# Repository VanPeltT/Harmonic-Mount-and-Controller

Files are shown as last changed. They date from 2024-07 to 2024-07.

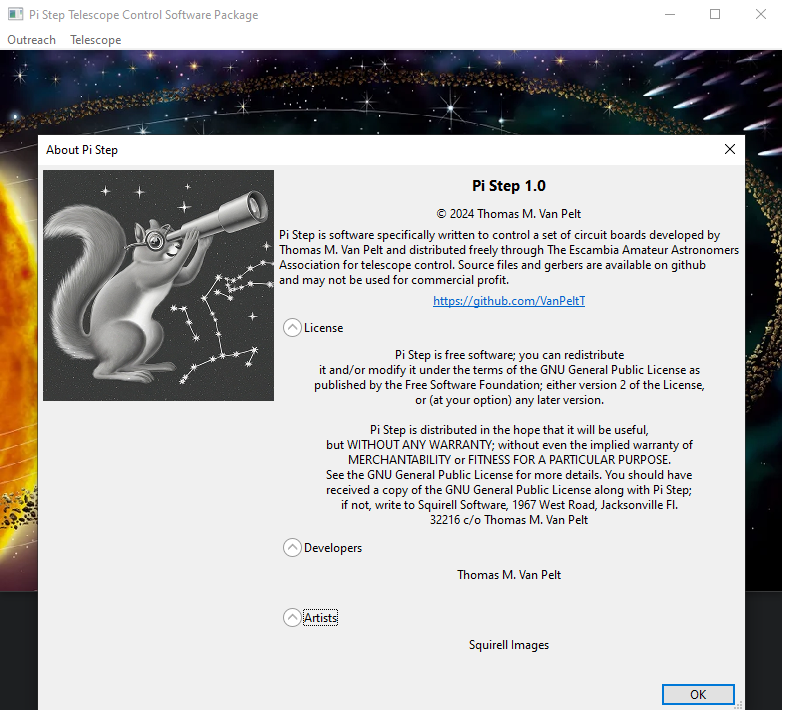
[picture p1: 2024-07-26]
Bonus And Future/Pi Step About.png

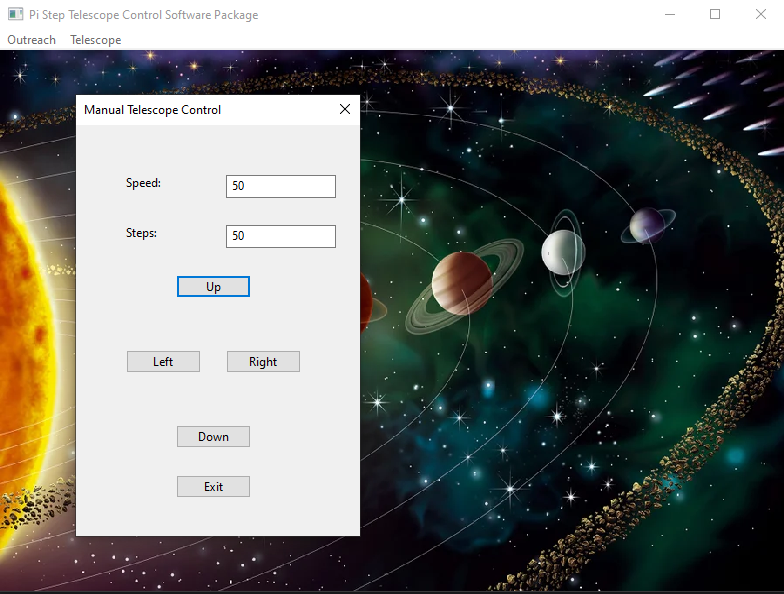
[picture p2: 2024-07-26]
Bonus And Future/Pi Step Manual Control.png

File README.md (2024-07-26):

# Harmonic Drive Telescope Mounts
# A DIY Approach to Precision Astronomical Viewing and Astrophotography
 
 This project, developed by Thomas Van Pelt and Greg Booher, consists of two
 harmonic drive telescope mounts designed for precise astronomical observations. 
 The project showcases both a robust, aluminum-based mount and a more 
 lightweight, entirely 3D-printed variant.

# Overview

  Target Audience: This document is intended for hobbyists, makers, and astronomers 
  interested in building their own high-performance telescope mounts.

# Project Goals:

  Develop affordable, customizable telescope mounts using harmonic drive technology.
  Offer a lightweight and portable 3D-printed option.
  Provide detailed documentation and open-source designs for community use.
  Achieve precise pointing and tracking for astrophotography applications.

# Unique Selling Points:

  Cost-effective: Harmonic drive technology offers high precision at a reasonable 
      cost compared to traditional gear drives.
  Customizable: Modular design allows for adaptations based on telescope weight 
      and user needs.
  Open-source: Hardware and software designs are freely available for modification 
      and improvement.

# Mounts Description

# Mount 1: Aluminum Anodized Mount

  Material: Aluminum (anodized by Greg Booher)
  Motors: 2 NEMA 17 motors with a 27:1 gearbox
  Harmonic Drive: CSF-17-100-2UH-LW with a 100:1 reduction
  Controllers: TMC2209 stepper controllers
  Microcontroller: Teensy 4.0 running OnStep
  Connectivity: Bluetooth and WiFi
  Design Contributions:
    Greg Booher: Machining and Anodizing the aluminum parts
    Thomas Van Pelt: Designing and creating the covers and printed circuit boards

# Mount 2: 3D Printed Mount

  Material: CF-PETG (Carbon Fiber Polyethylene Terephthalate Glycol)
  Motors: 2 NEMA 17 motors with a 30:1 harmonic drive
  Controllers: Same PCB control board as the larger mount
  Connectivity: Bluetooth and WiFi
  Design Contributions: Entirely designed and 3D printed

# Development Timeline

  The project has been under development for over six months and was demonstrated 
  to the Escambia Amateur Astronomy Association in July 2024.

# Future Work
  Thomas Van Pelt plans to further develop the larger mount, integrating it with a 
  custom PCB and software specifically designed for the Raspberry Pi, enhancing the 
  mount's control capabilities and user interface.

# Getting Started

# Prerequisites:

  Teensy 4.0
  TMC2209 stepper controllers
  NEMA 17 motors
  CSF-17-100-2UH-LW harmonic drive for the aluminum mount (or equivalent 100:1 harmonic drive)
  30:1 harmonic drive for the 3D printed mount
  OnStep firmware
  Bluetooth and WiFi modules
  
# Assembly Instructions:

  1. Assemble the aluminum frame.
  2. Install the NEMA 17 motors and the 27:1 gearbox.
  3. Integrate the CSF-17-100-2UH-LW harmonic drive.
  4. Connect the TMC2209 stepper controllers to the Teensy 4.0.
  5. Connect the Bluetooth and WiFi modules to the Teensy 4.0.
  6. Upload OnStep firmware to the Teensy 4.0.
  7. Install the covers and PCBs designed by Thomas.

# Usage:

  1. Power on the system.
  2. Connect the mount to your computer or control device via Bluetooth or WiFi.
  3. Use OnStep software to control the telescope mount. (OnStep download and 
      configuration instructions can be found online)
  4. Adjust settings as necessary for precise astronomical tracking and observation.

# Contribution

  Contributions to further enhance the mounts are welcome. Please fork the 
  repository and submit pull requests.

# License

  This project is licensed under the MIT License.

  For more detailed information, please refer to the documentation in the repository or contact the developers:

  Thomas Van Pelt
  Greg Booher
  
  Happy Stargazing!

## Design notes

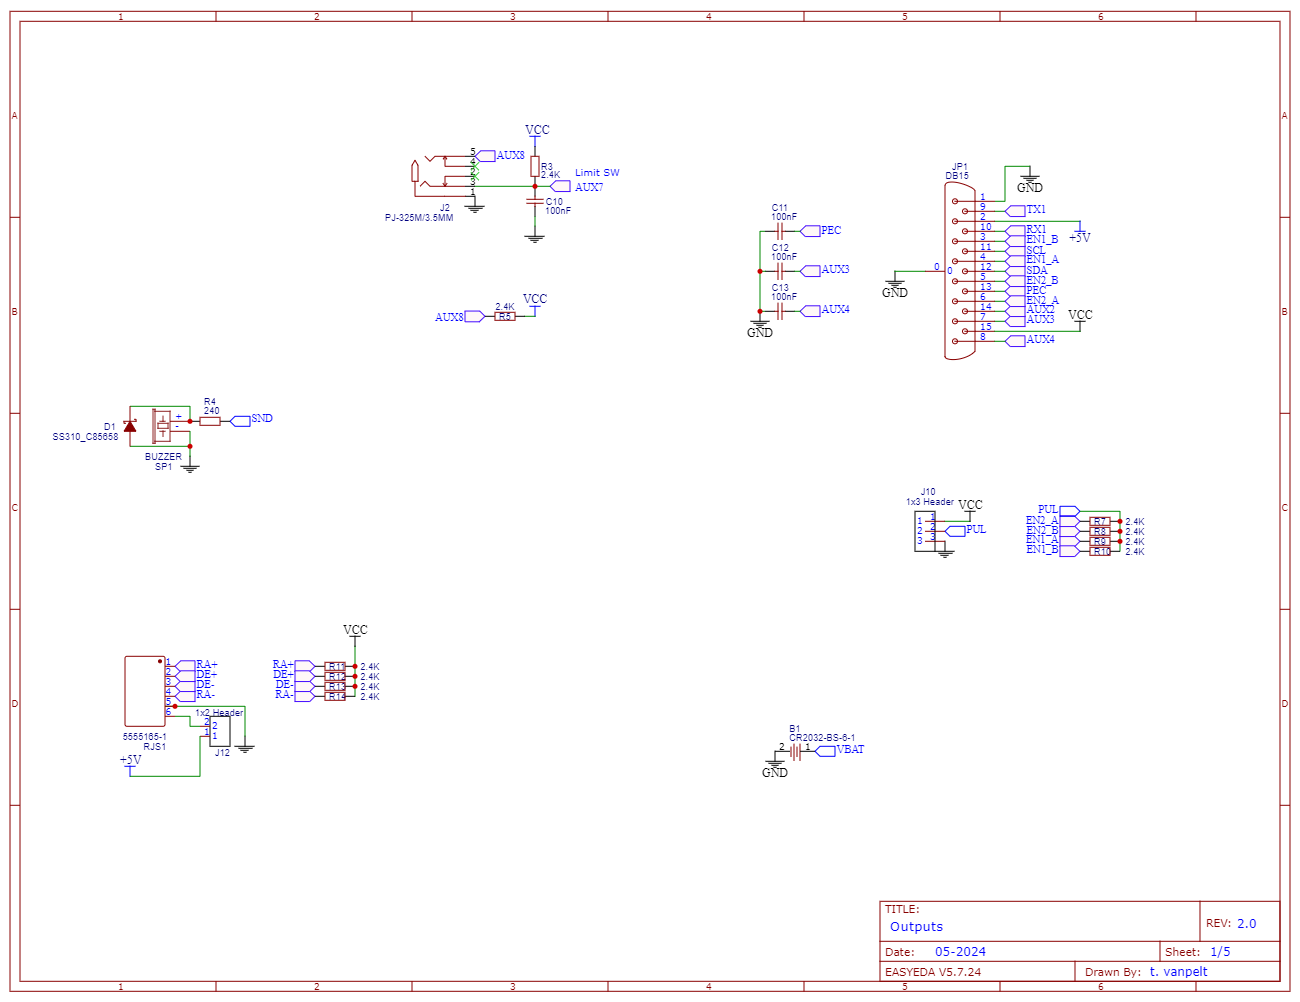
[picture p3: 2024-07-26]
Electronics/Outputs.png

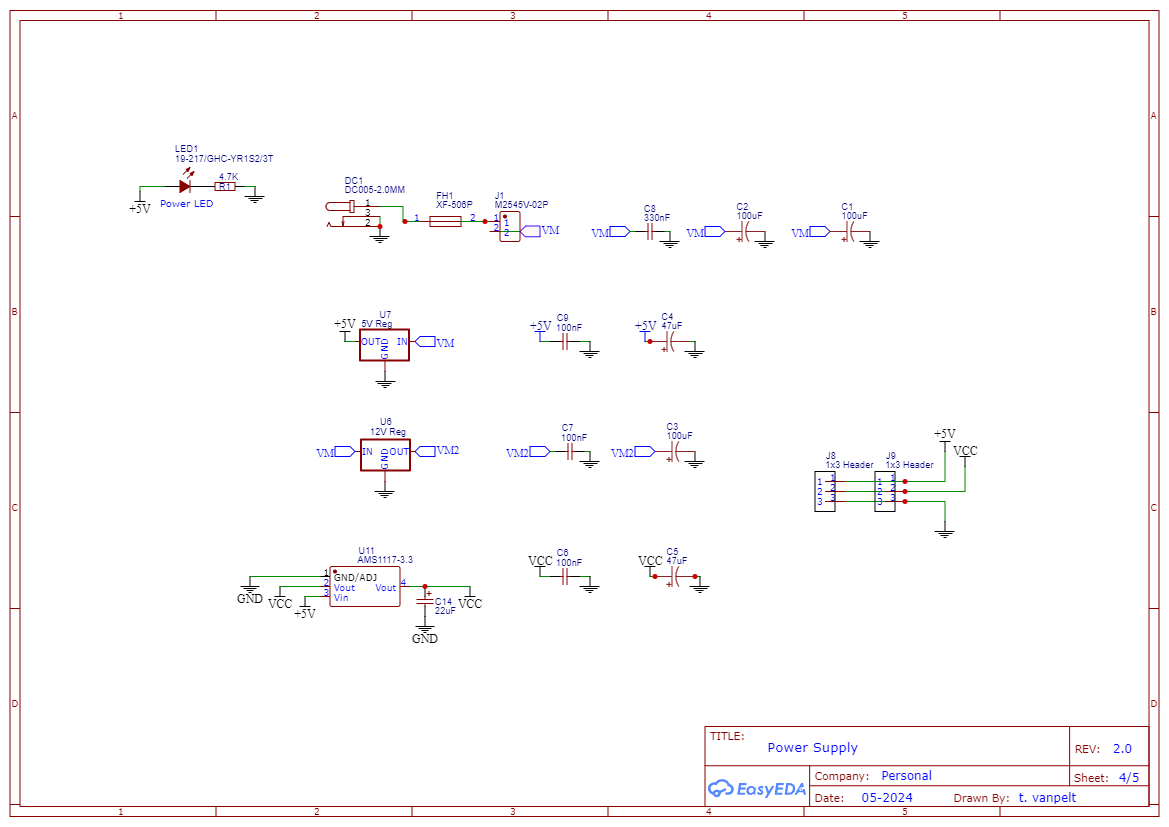
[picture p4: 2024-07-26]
Electronics/PowerSupply.png

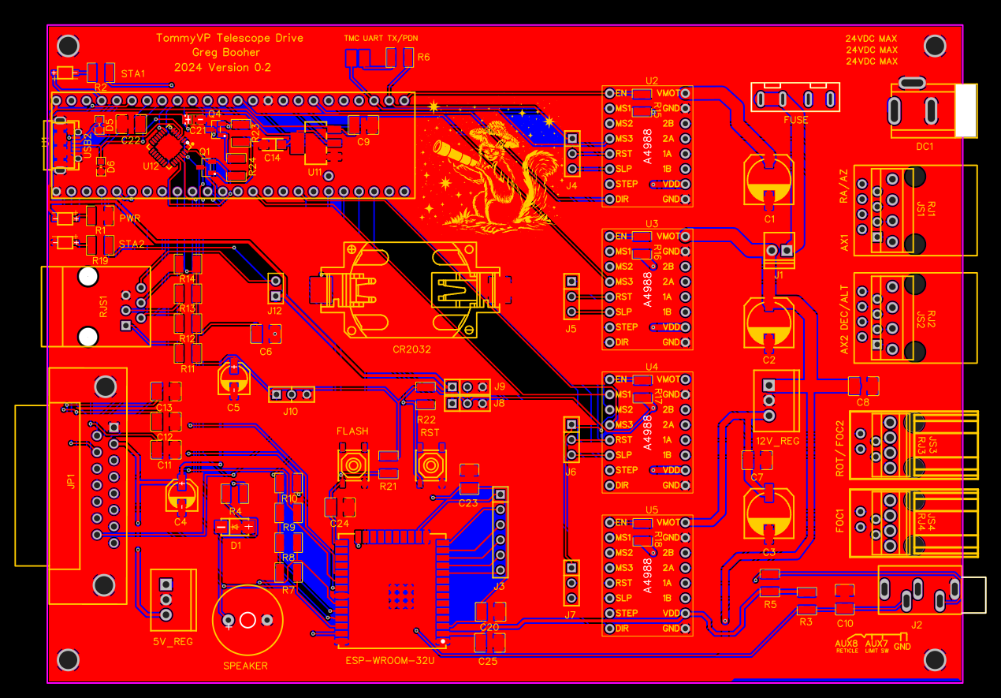
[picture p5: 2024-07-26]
Electronics/PCB_New-Board_2024-07-25.png

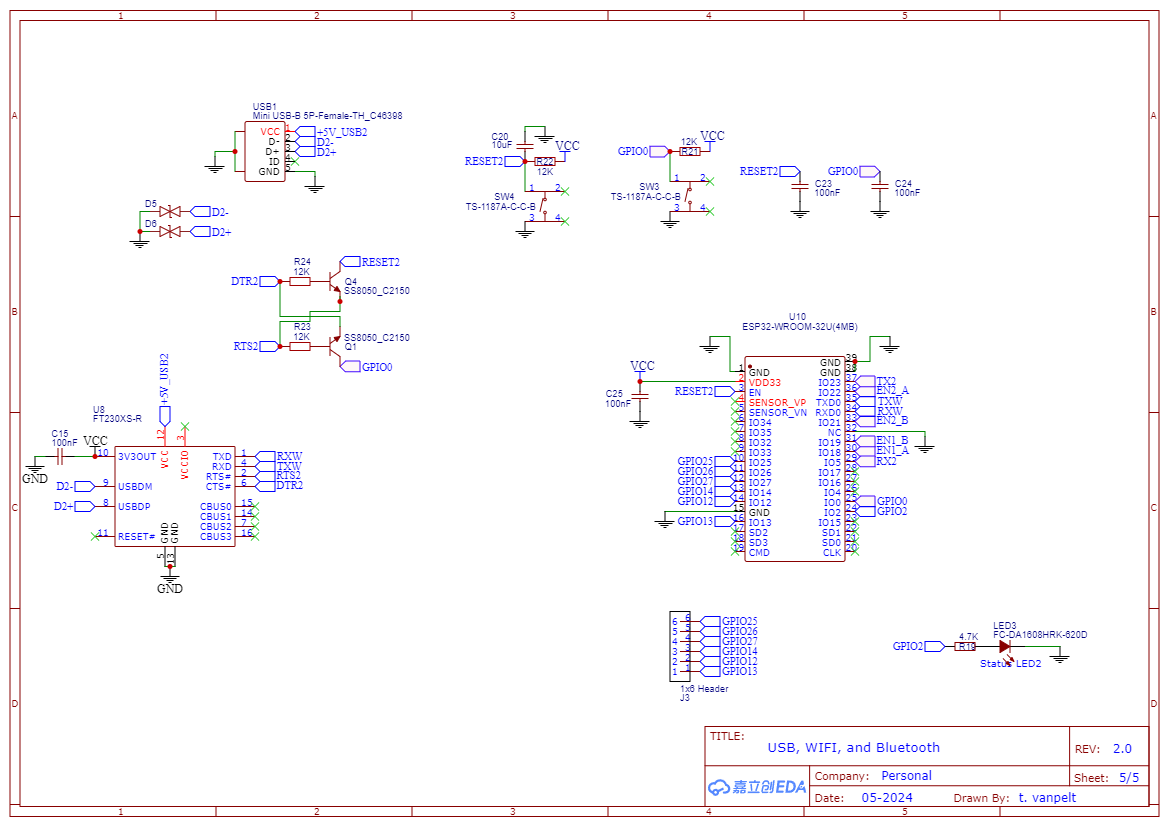
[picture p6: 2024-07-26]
Electronics/USBWIFIBT.png

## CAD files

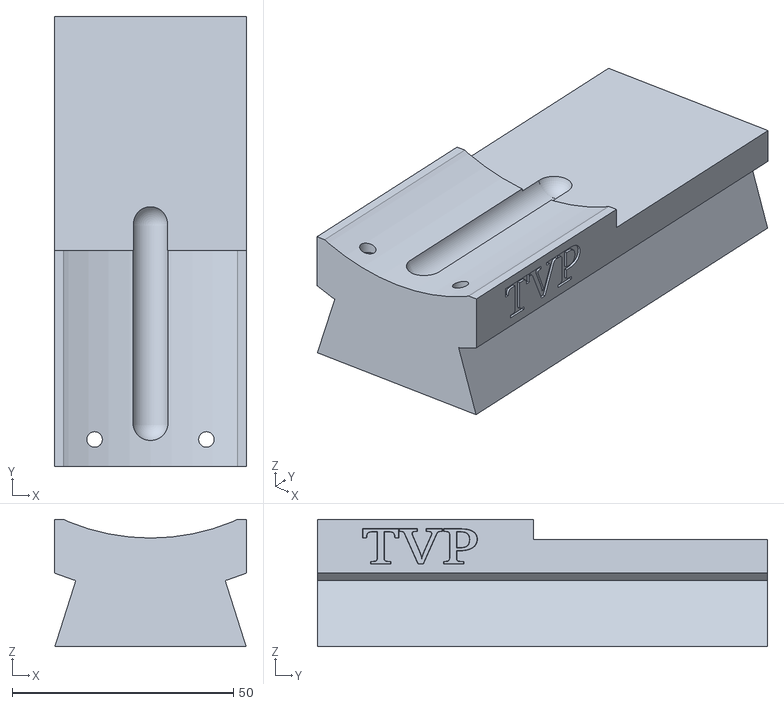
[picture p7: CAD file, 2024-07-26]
Bonus And Future/Orange-Tube-C90_Mount.stl
43.4 x 101.6 x 28.7

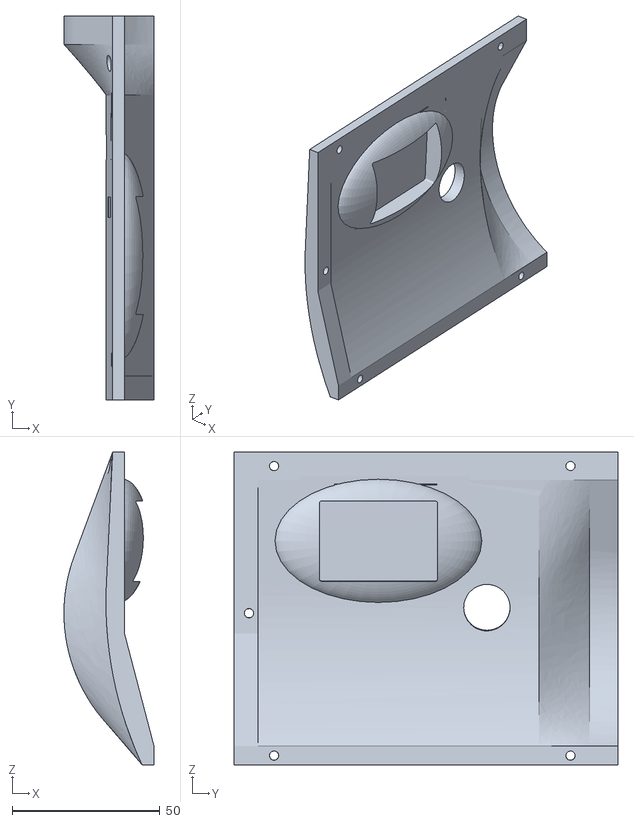
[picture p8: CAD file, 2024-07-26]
Harmonic Mount/3D Gerbers for Harmonic Mount/RA Shell Right.stl
30.5 x 129.8 x 105.9

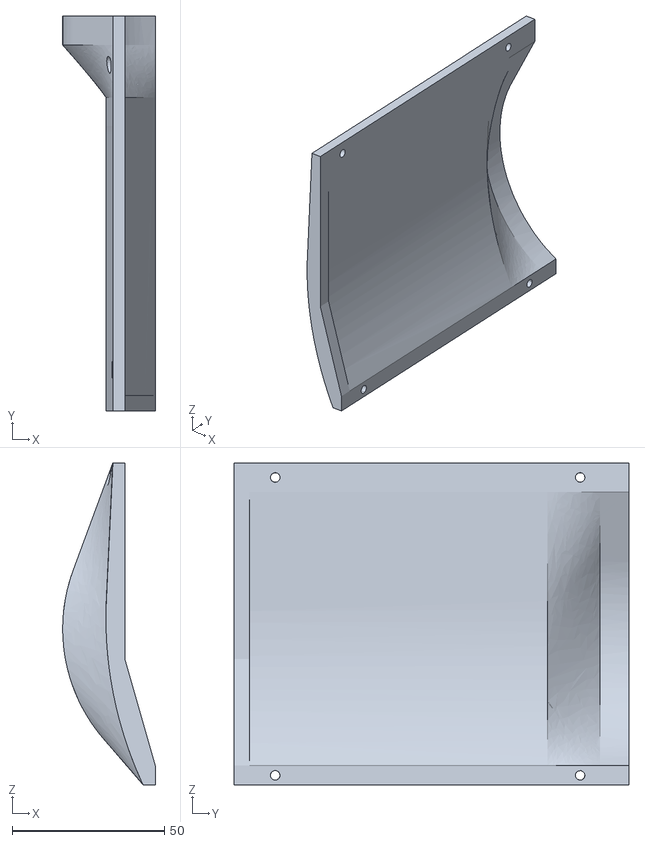
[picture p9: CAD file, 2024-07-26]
Harmonic Mount/3D Gerbers for Harmonic Mount/DEC Shell Right.stl
30.5 x 129.8 x 105.9

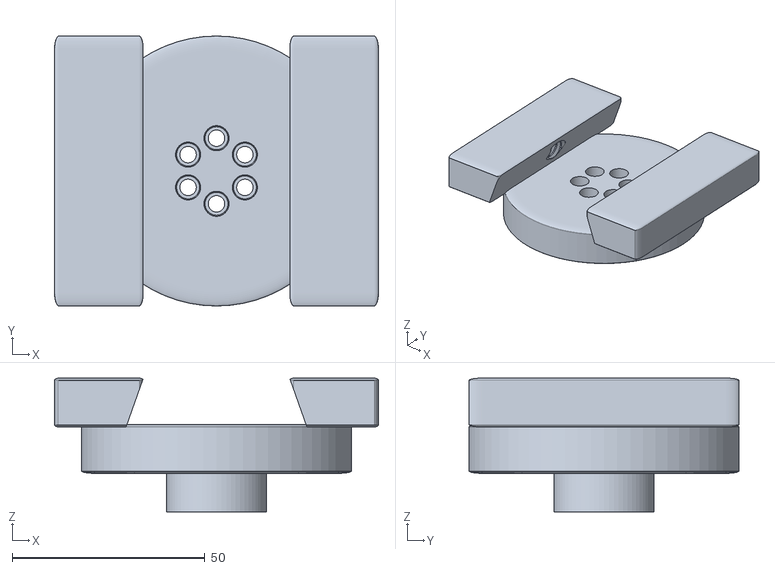
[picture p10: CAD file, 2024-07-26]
Mini Mount/Mini Mount Head 2.stl
84.0 x 70.0 x 34.7

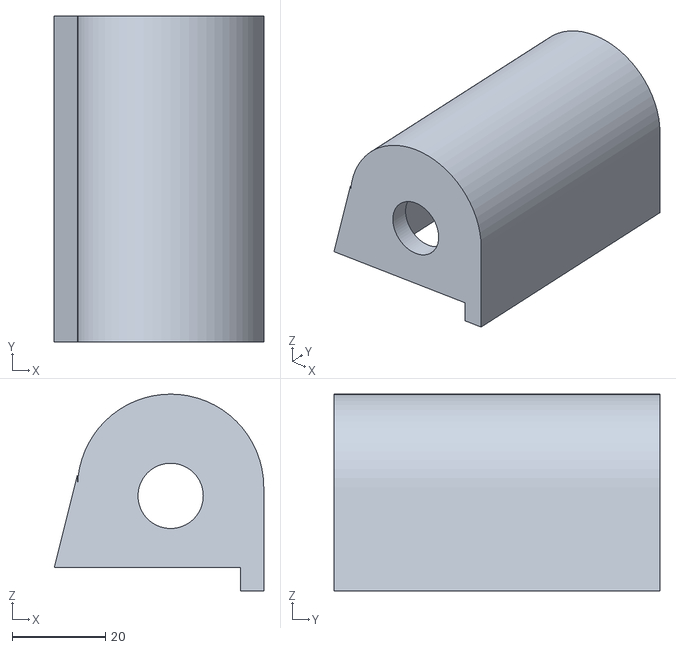
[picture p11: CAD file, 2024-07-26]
Mini Mount/Mini Mount Brace.stl
45.0 x 70.0 x 42.2

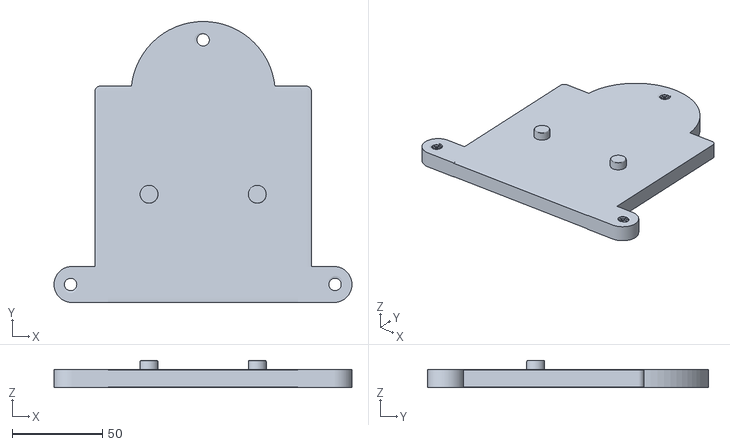
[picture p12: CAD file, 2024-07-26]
Mini Mount/Mini Mount Level Base.stl
165.2 x 155.8 x 15.0

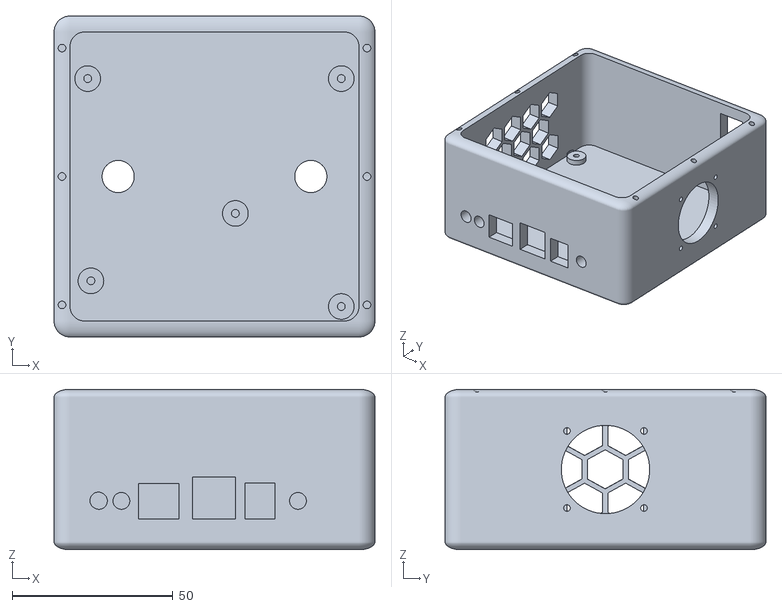
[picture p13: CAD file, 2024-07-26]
Mini Mount/Mini Mount Electronics Housing.stl
100.0 x 100.0 x 50.0

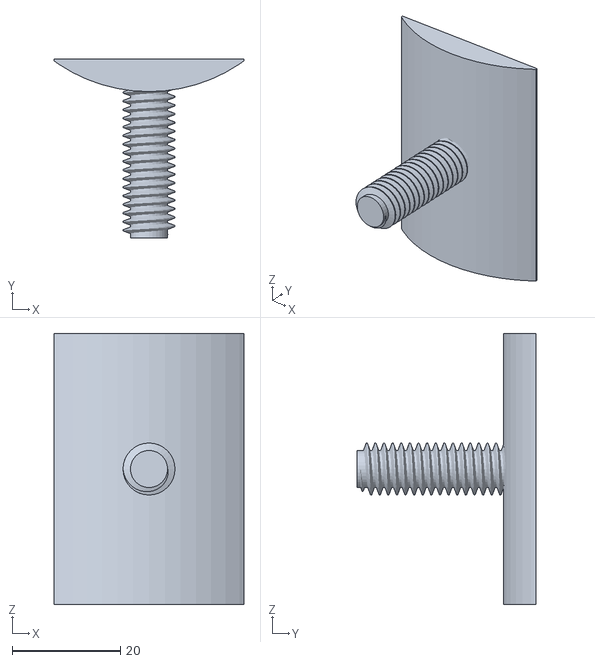
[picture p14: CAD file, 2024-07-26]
Mini Mount/Mini Mount Axis.stl
35.0 x 33.0 x 50.0

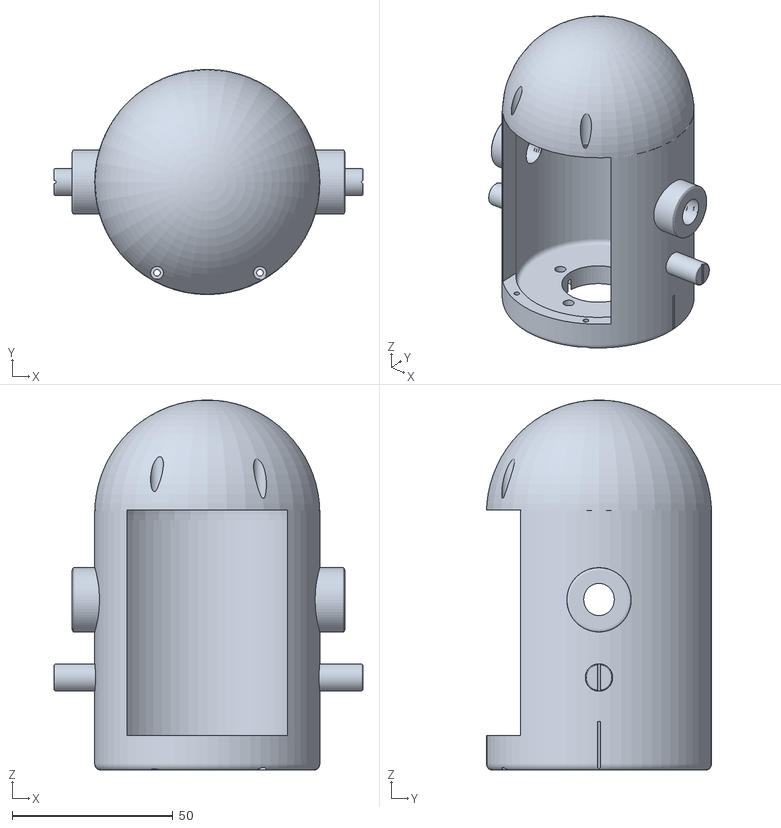
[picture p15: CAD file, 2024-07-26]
Mini Mount/Mini Mount Tail.stl
96.0 x 70.0 x 115.0

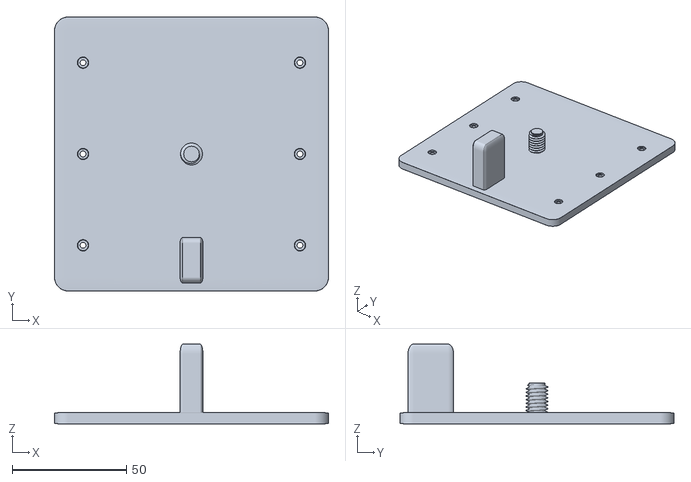
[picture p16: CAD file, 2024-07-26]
Mini Mount/Mini Mount Electronics Cover.stl
120.0 x 120.0 x 35.0

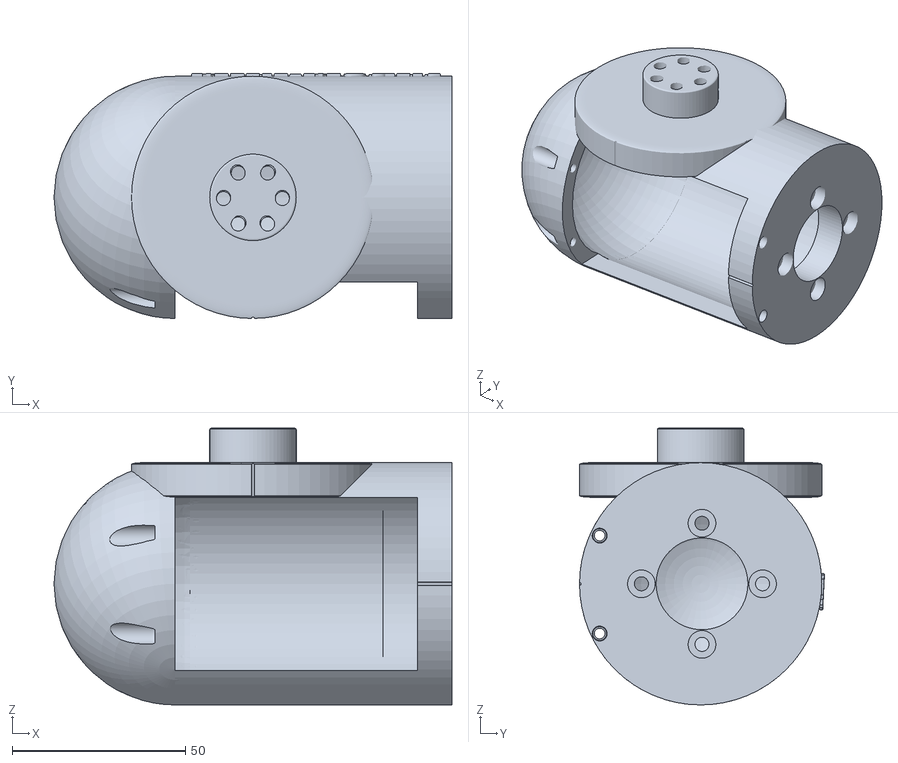
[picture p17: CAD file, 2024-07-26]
Mini Mount/Mini Mount Head 1.stl
115.0 x 70.8 x 80.0

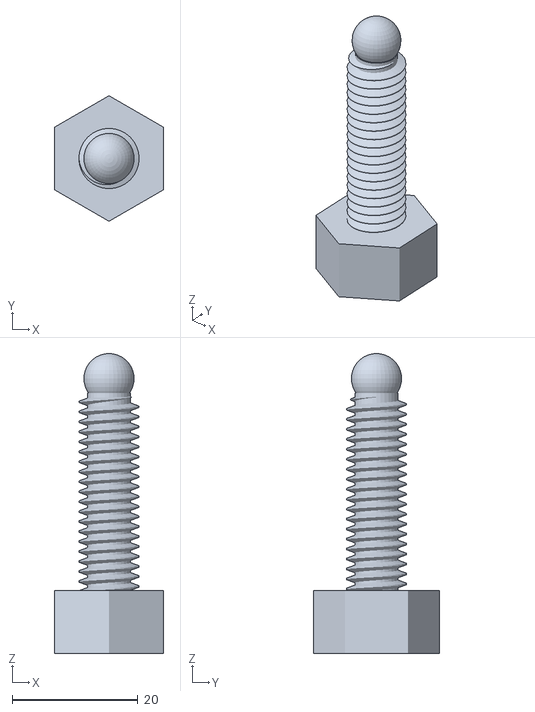
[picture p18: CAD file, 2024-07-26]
Mini Mount/Mini Mount Screw.stl
17.3 x 20.0 x 47.8

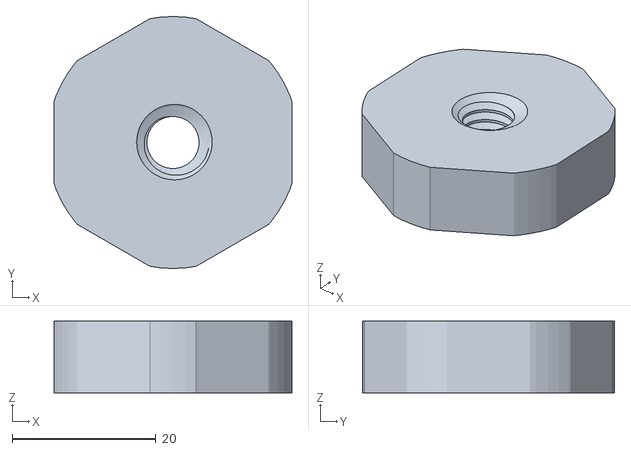
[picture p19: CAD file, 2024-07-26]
Mini Mount/Mini Mount Nut.stl
33.0 x 35.0 x 10.00

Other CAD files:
Harmonic Mount/3D Gerbers for Harmonic Mount/DEC Shell with Aviation Port.stl

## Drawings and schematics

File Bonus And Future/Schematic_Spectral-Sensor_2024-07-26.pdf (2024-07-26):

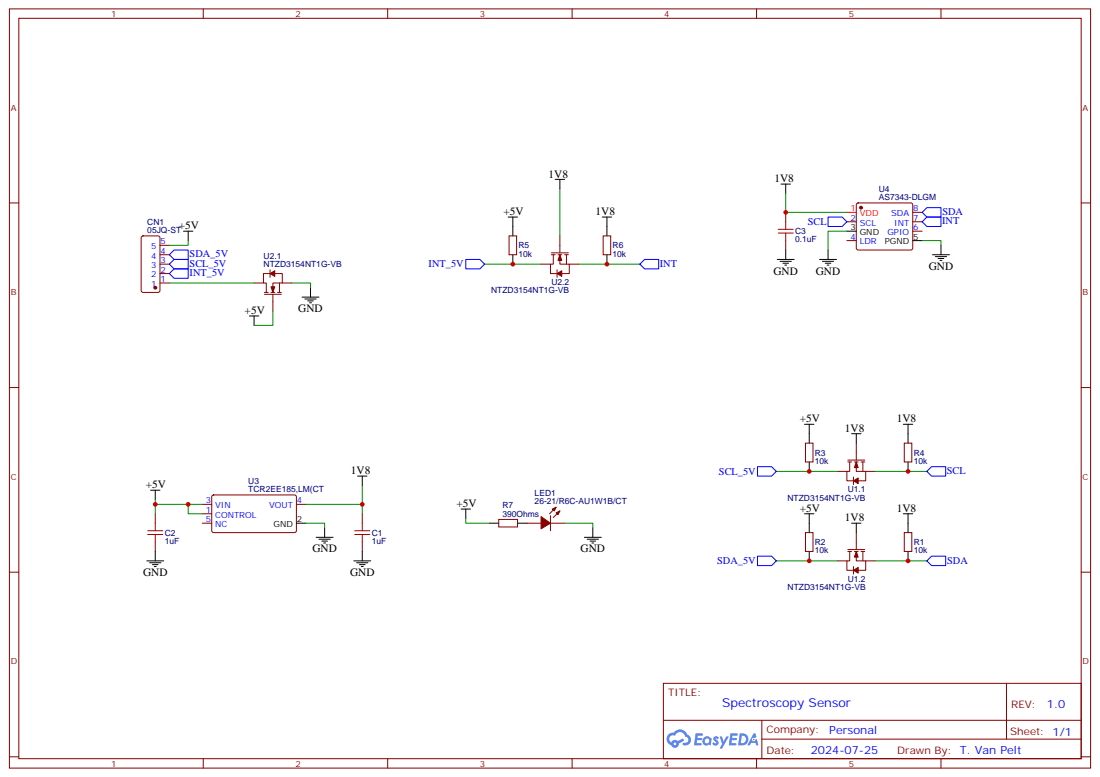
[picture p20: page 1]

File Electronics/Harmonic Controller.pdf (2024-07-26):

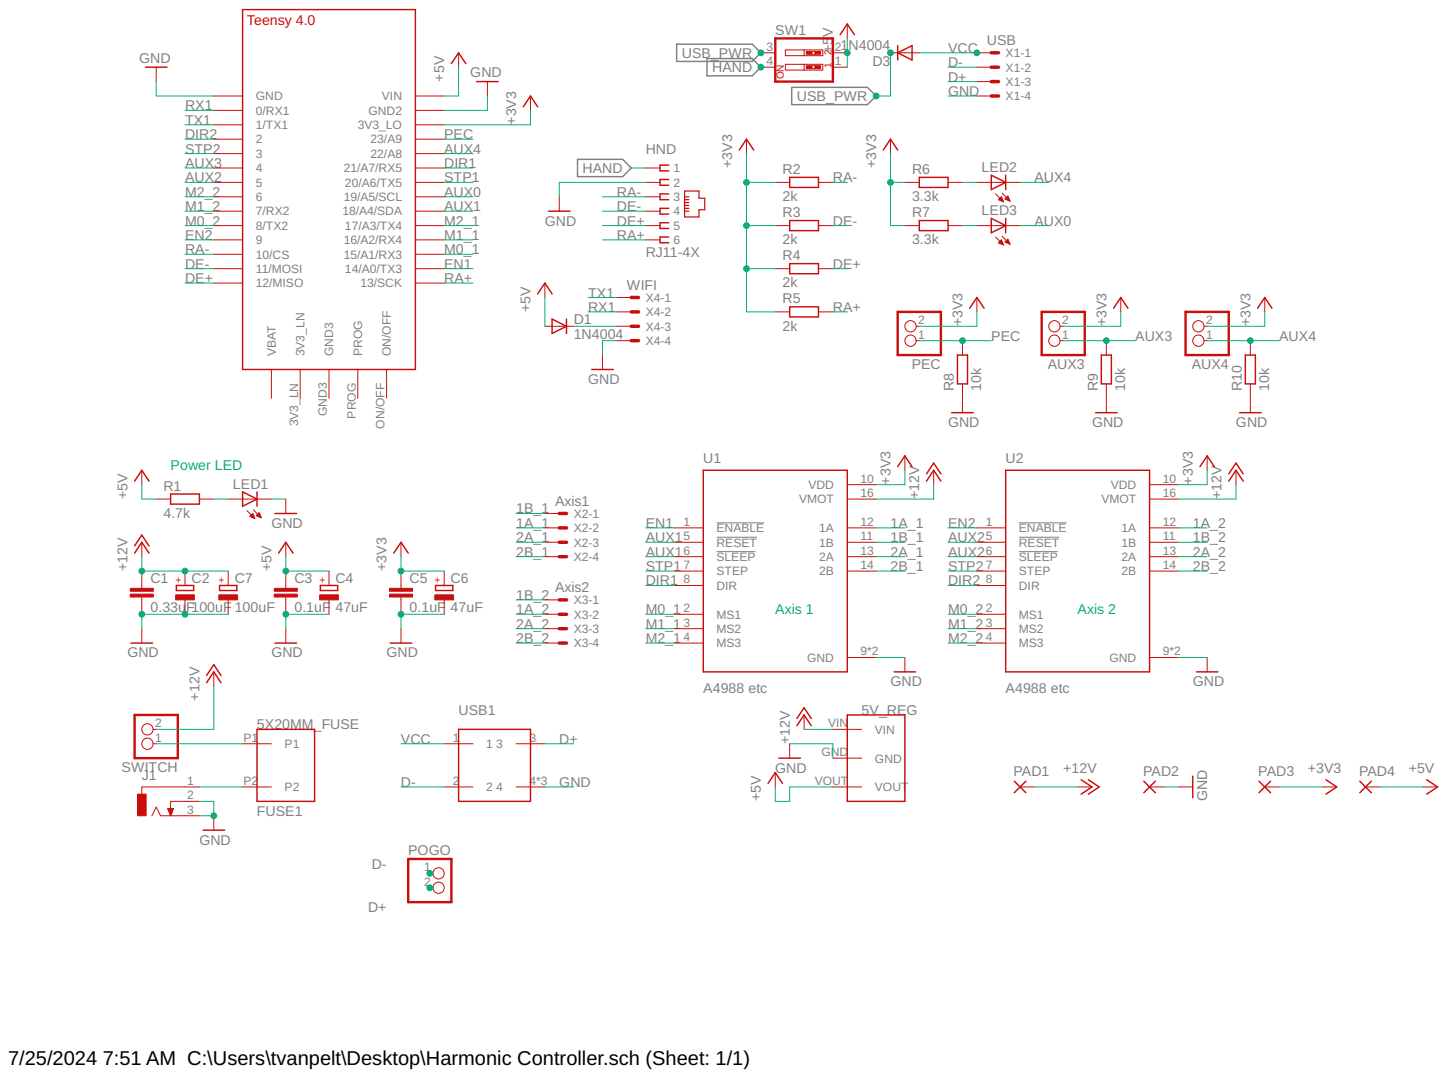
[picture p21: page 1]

ON/OFF

7/25/2024 7:51 AM C:\Users\tvanpelt\Desktop\Harmonic Controller.sch (Sheet: 1/1)

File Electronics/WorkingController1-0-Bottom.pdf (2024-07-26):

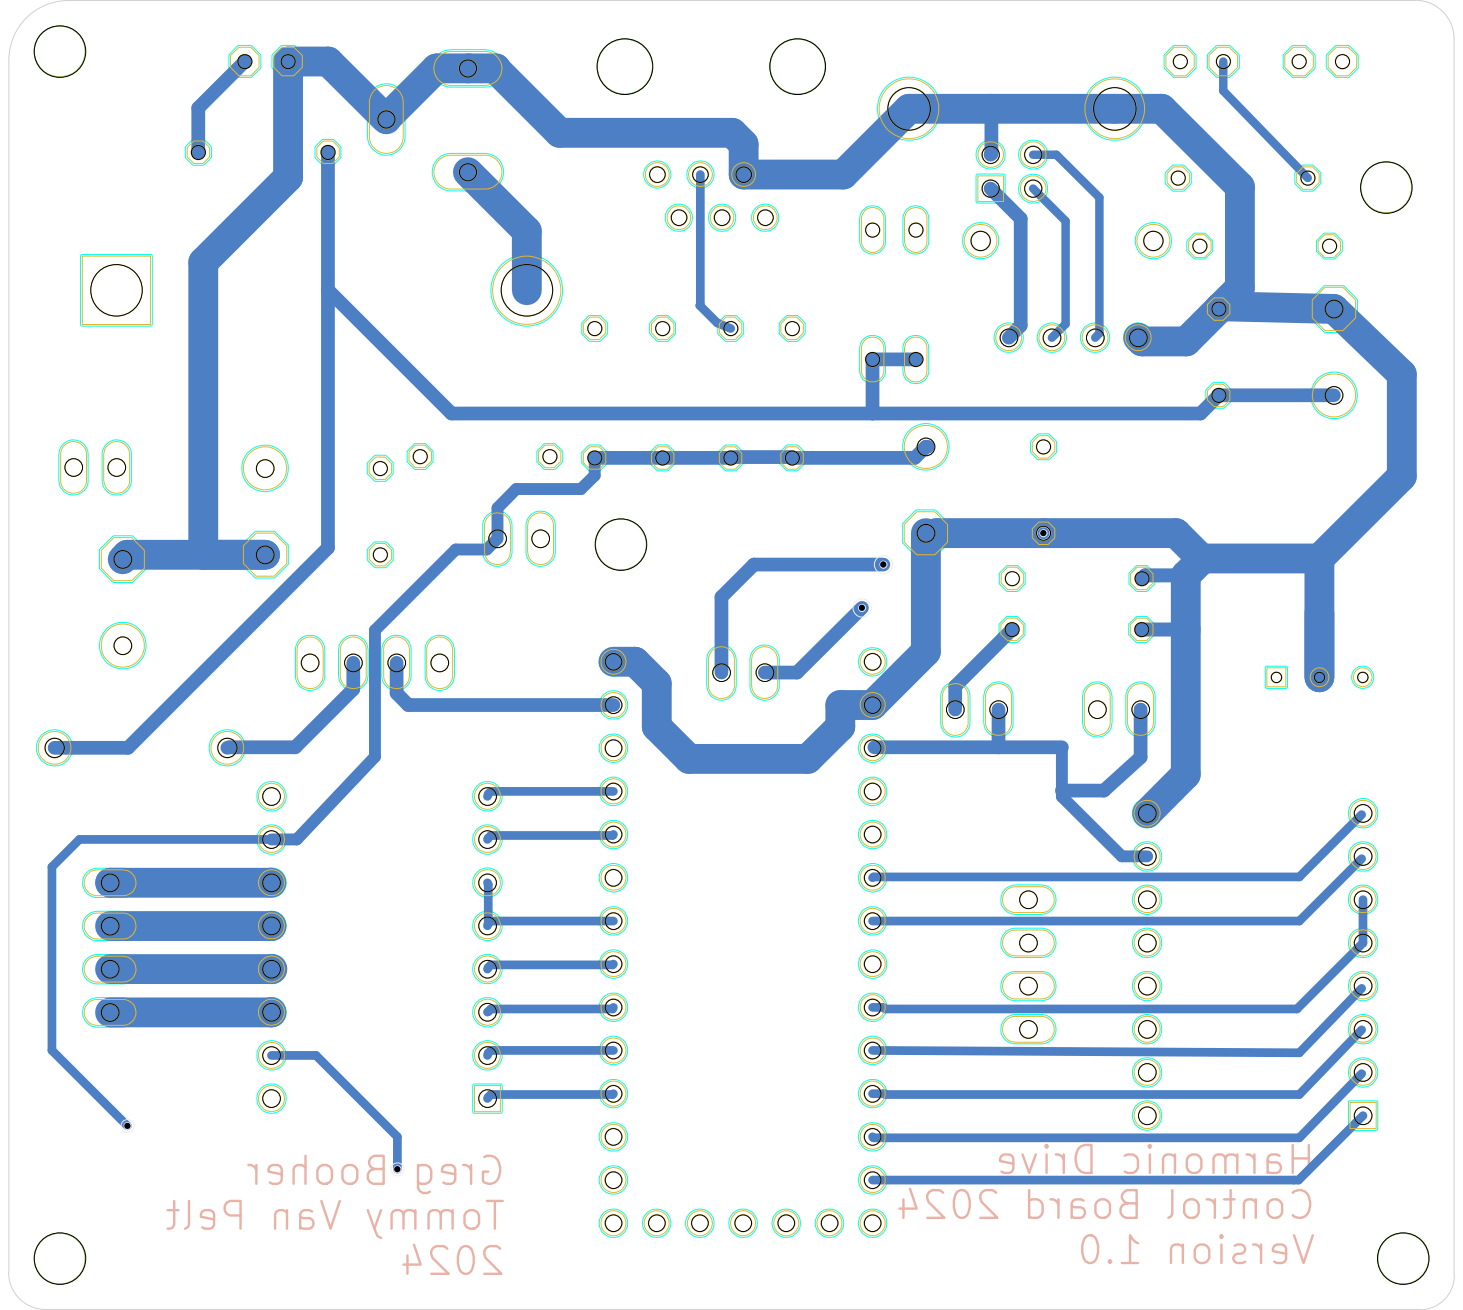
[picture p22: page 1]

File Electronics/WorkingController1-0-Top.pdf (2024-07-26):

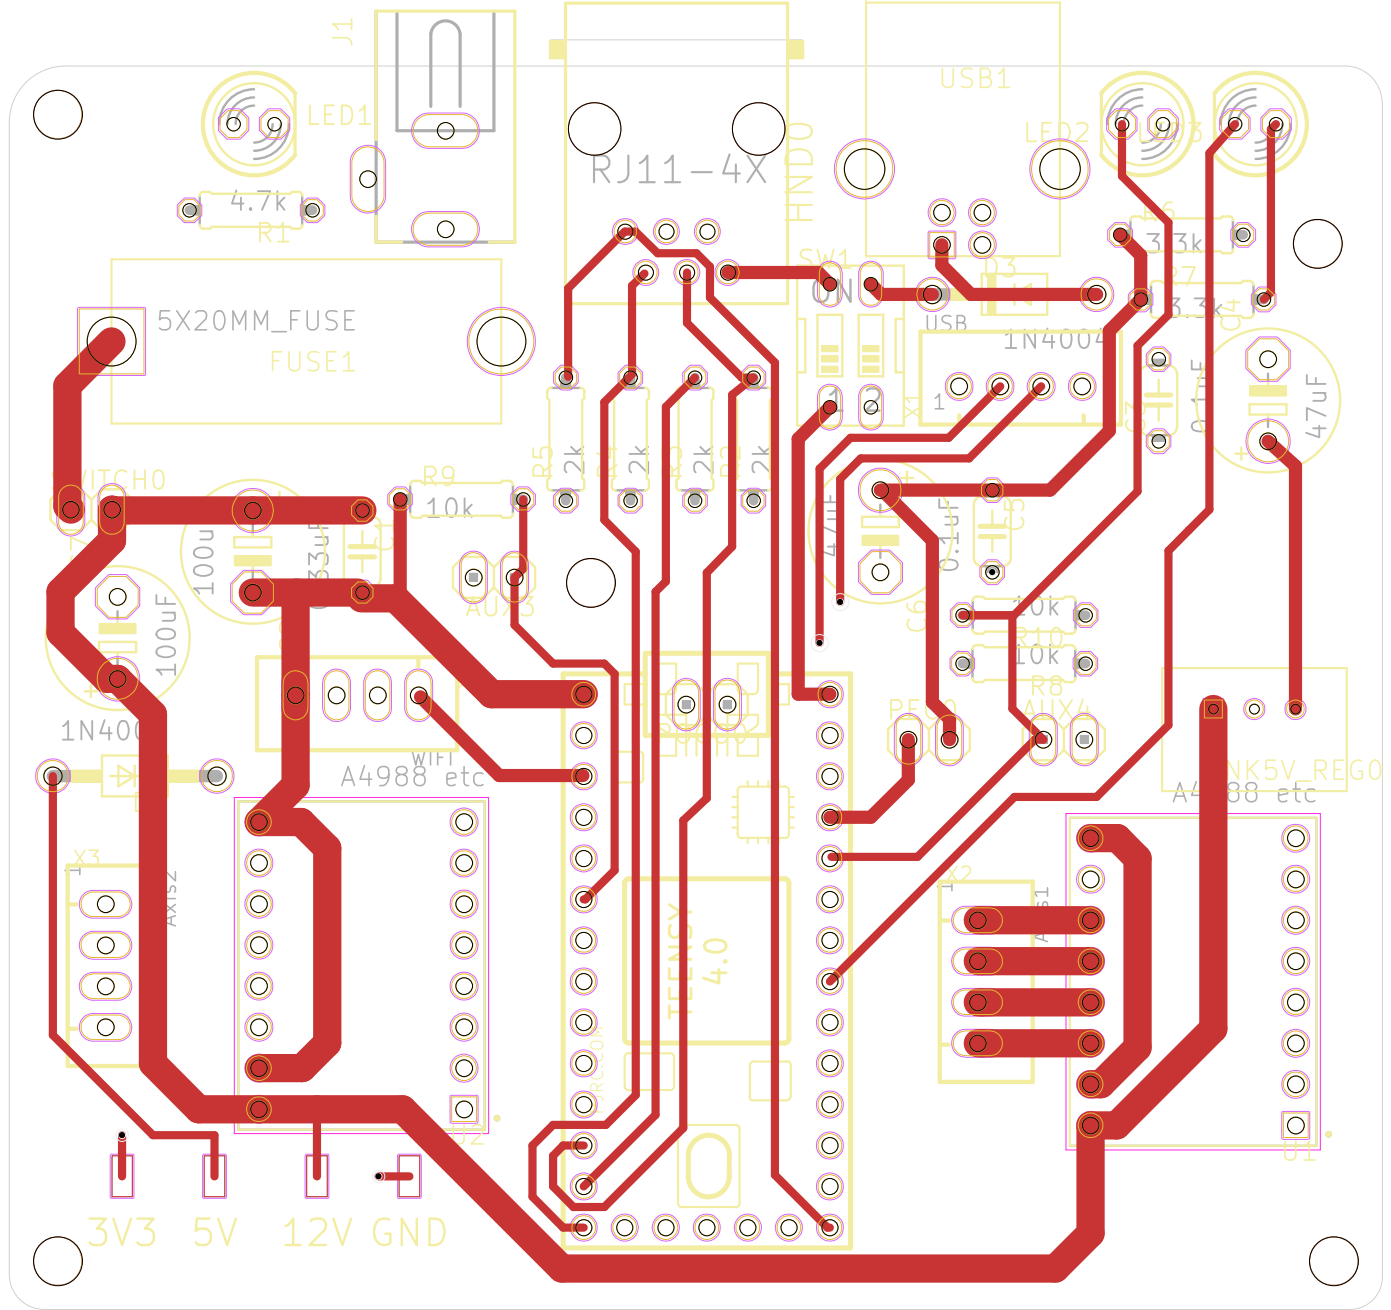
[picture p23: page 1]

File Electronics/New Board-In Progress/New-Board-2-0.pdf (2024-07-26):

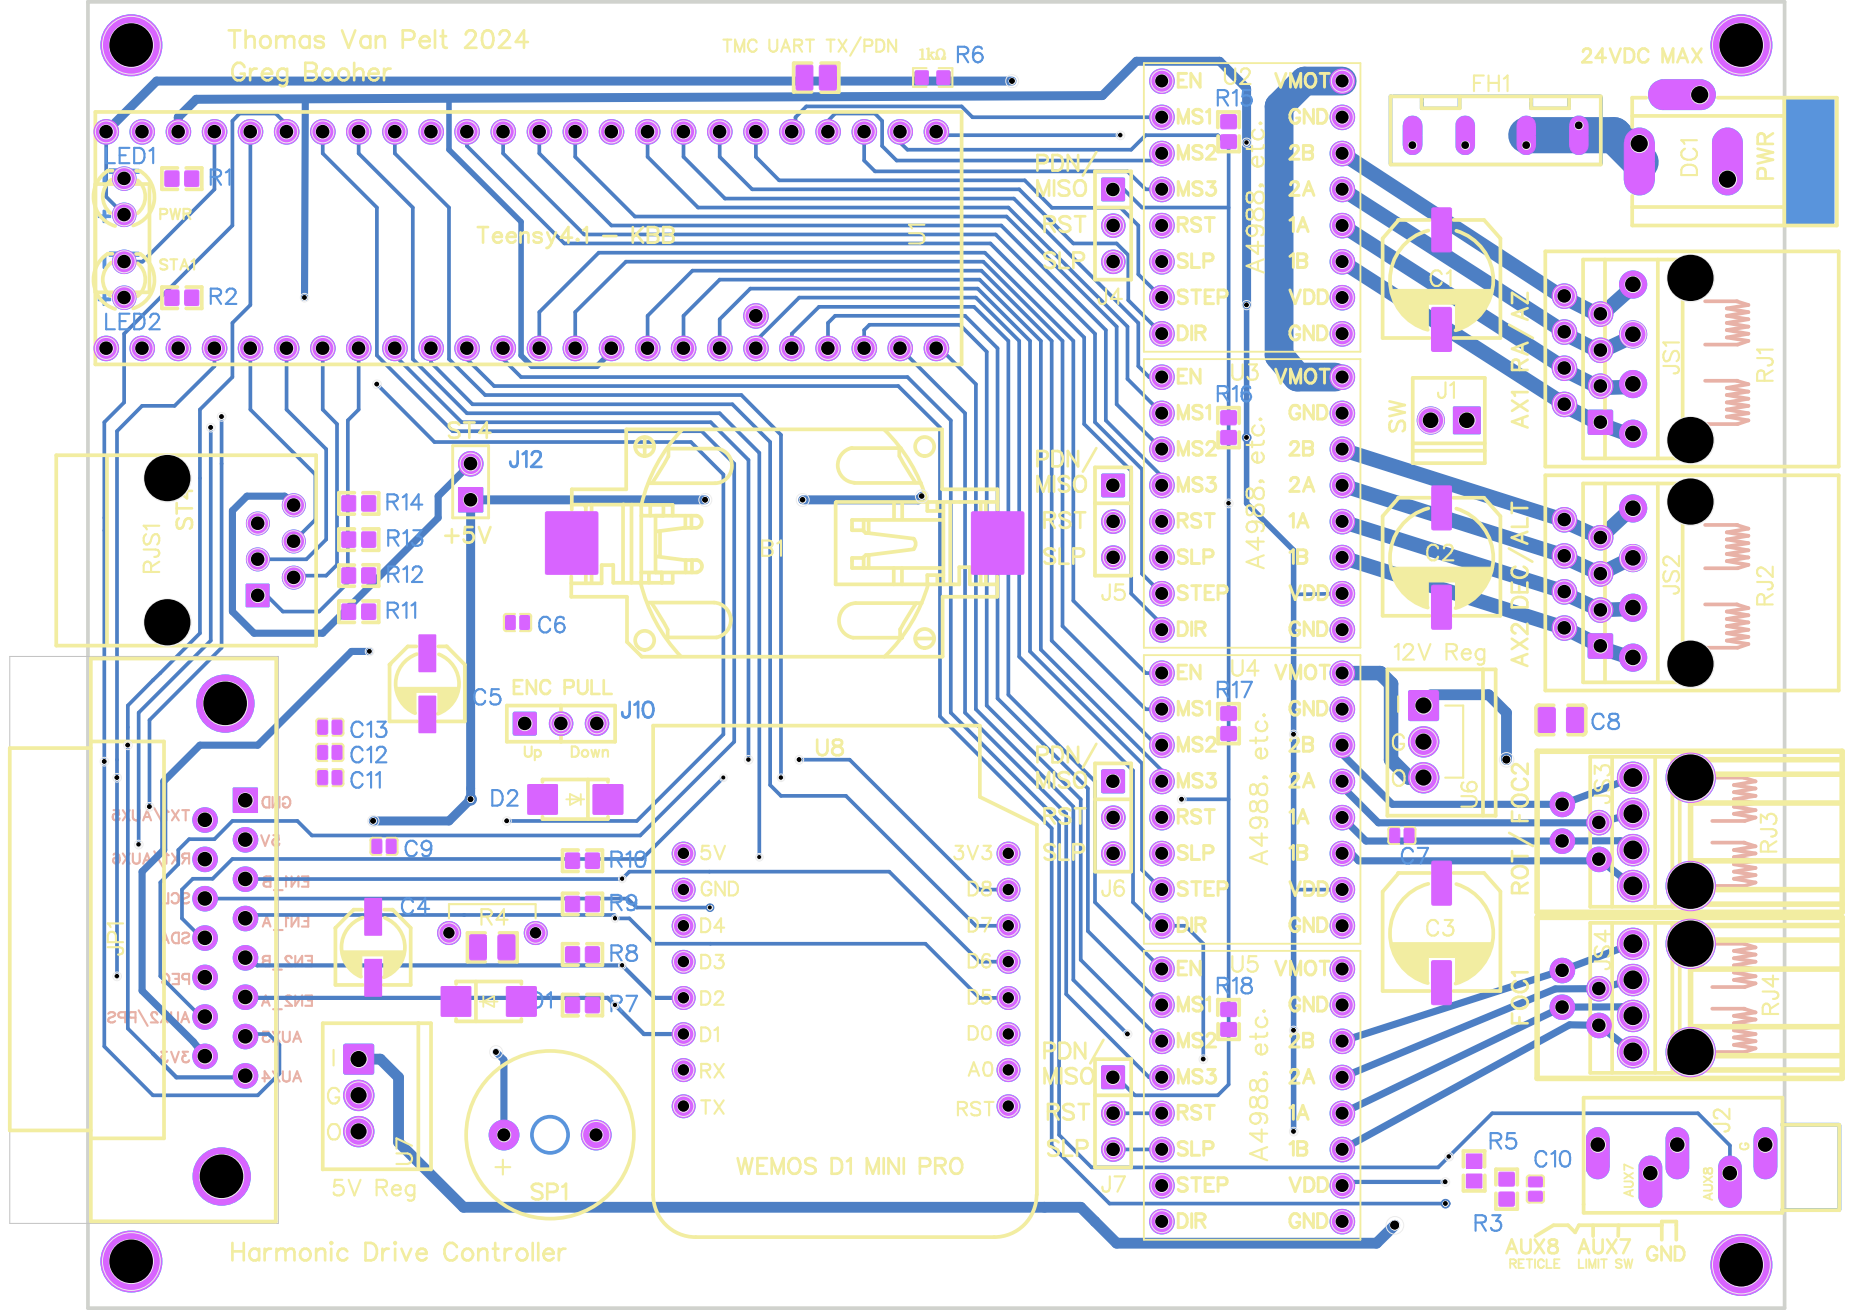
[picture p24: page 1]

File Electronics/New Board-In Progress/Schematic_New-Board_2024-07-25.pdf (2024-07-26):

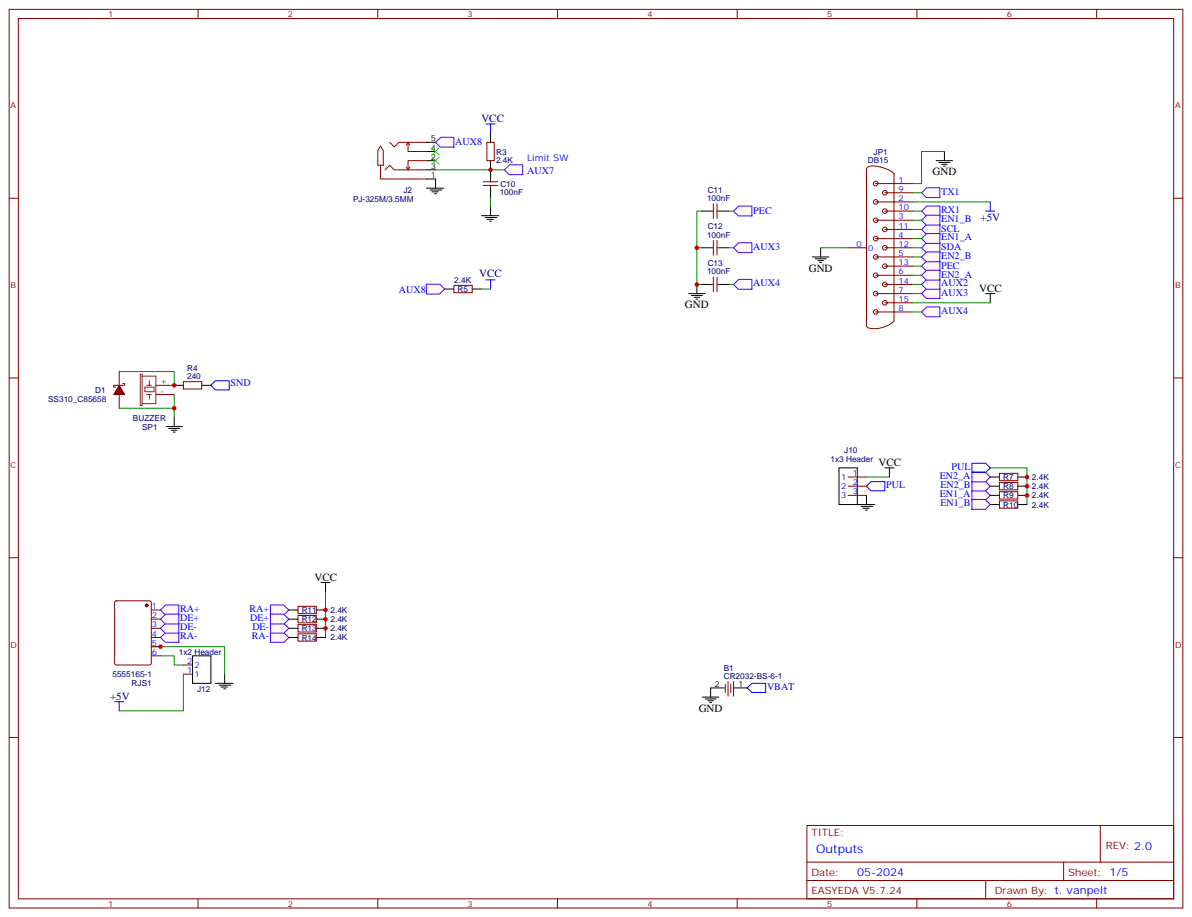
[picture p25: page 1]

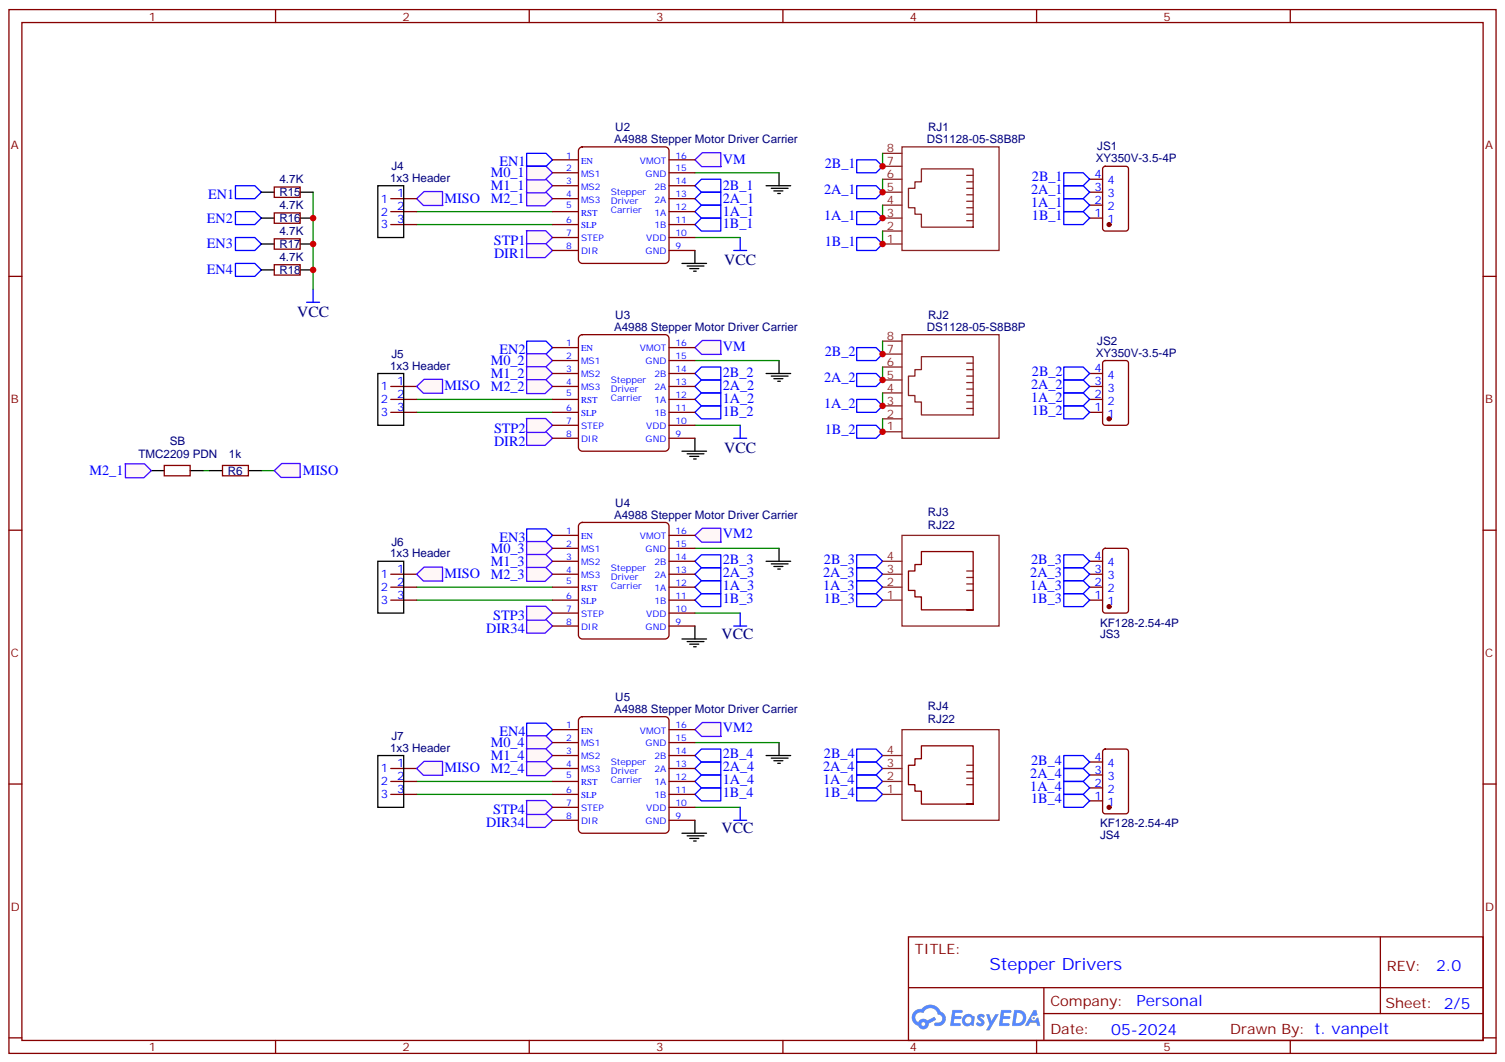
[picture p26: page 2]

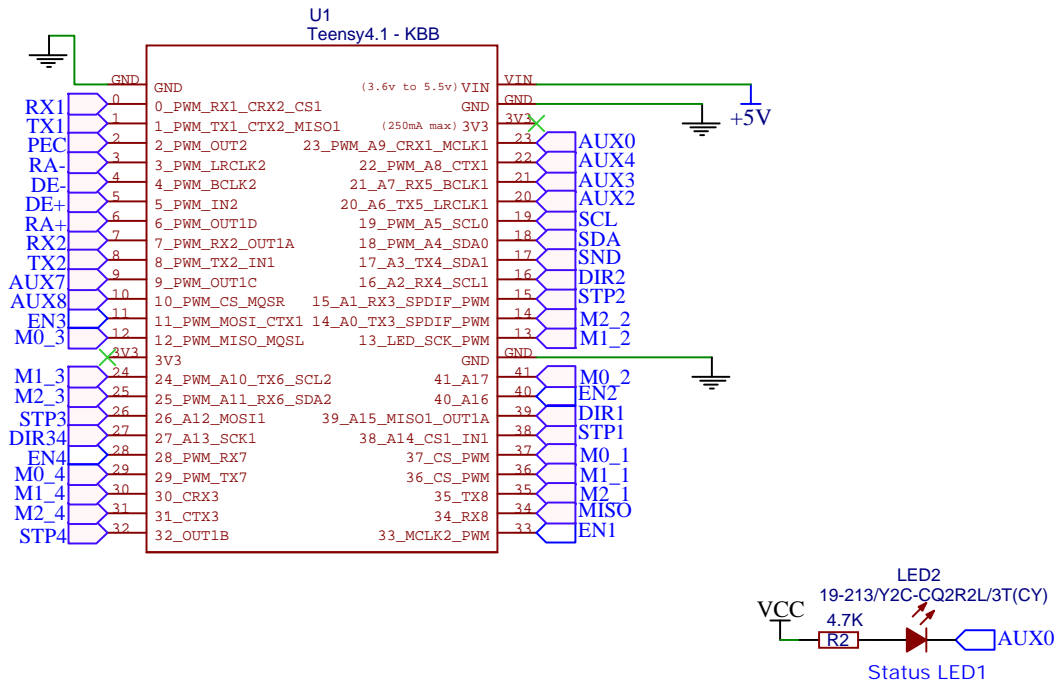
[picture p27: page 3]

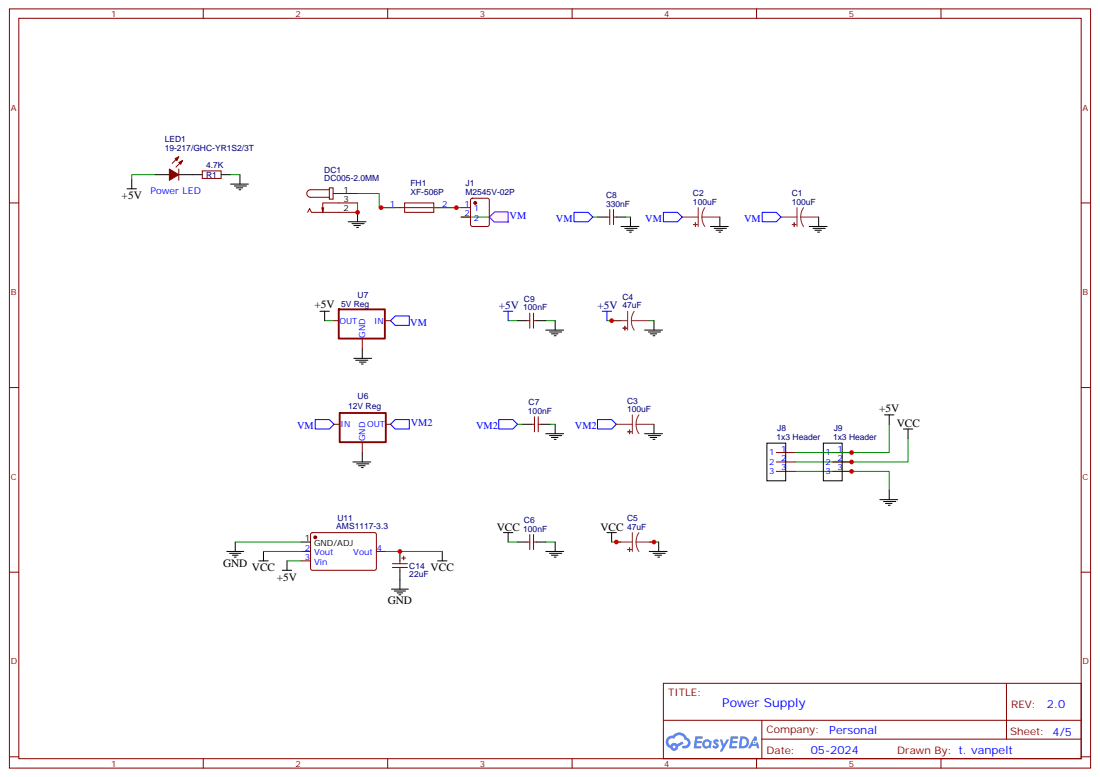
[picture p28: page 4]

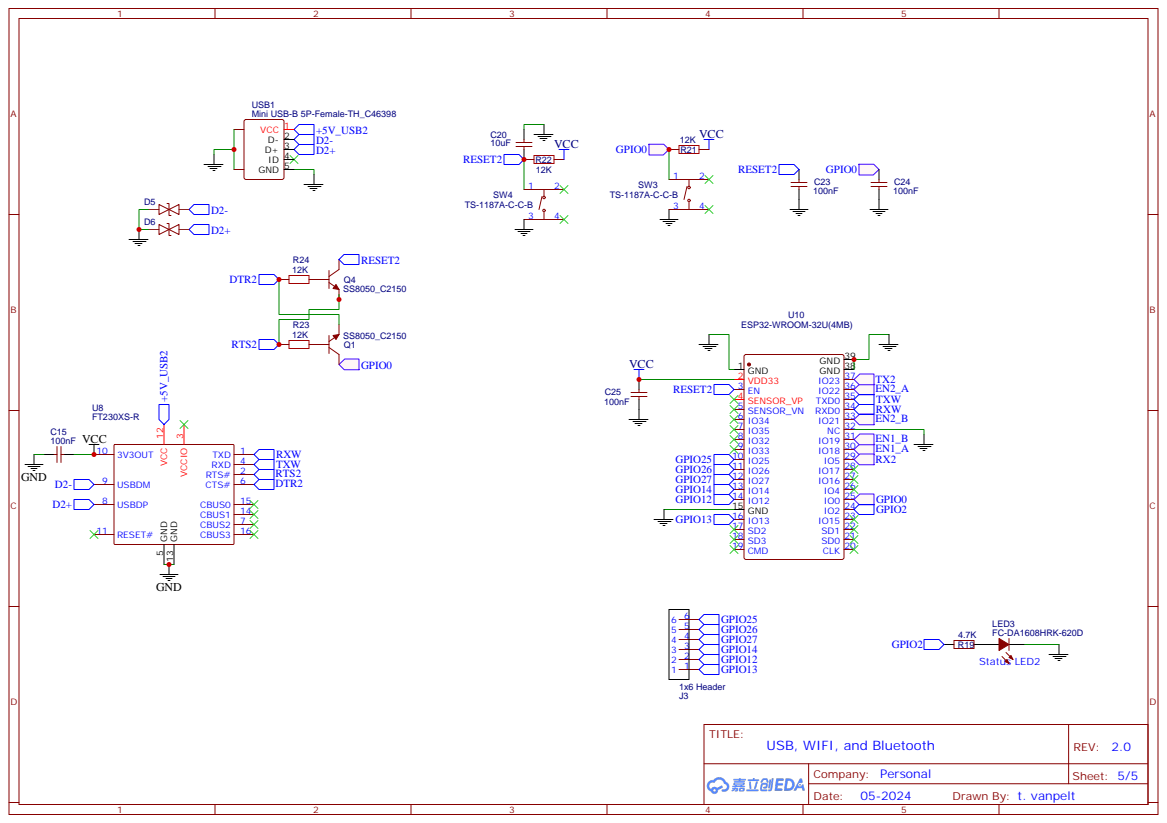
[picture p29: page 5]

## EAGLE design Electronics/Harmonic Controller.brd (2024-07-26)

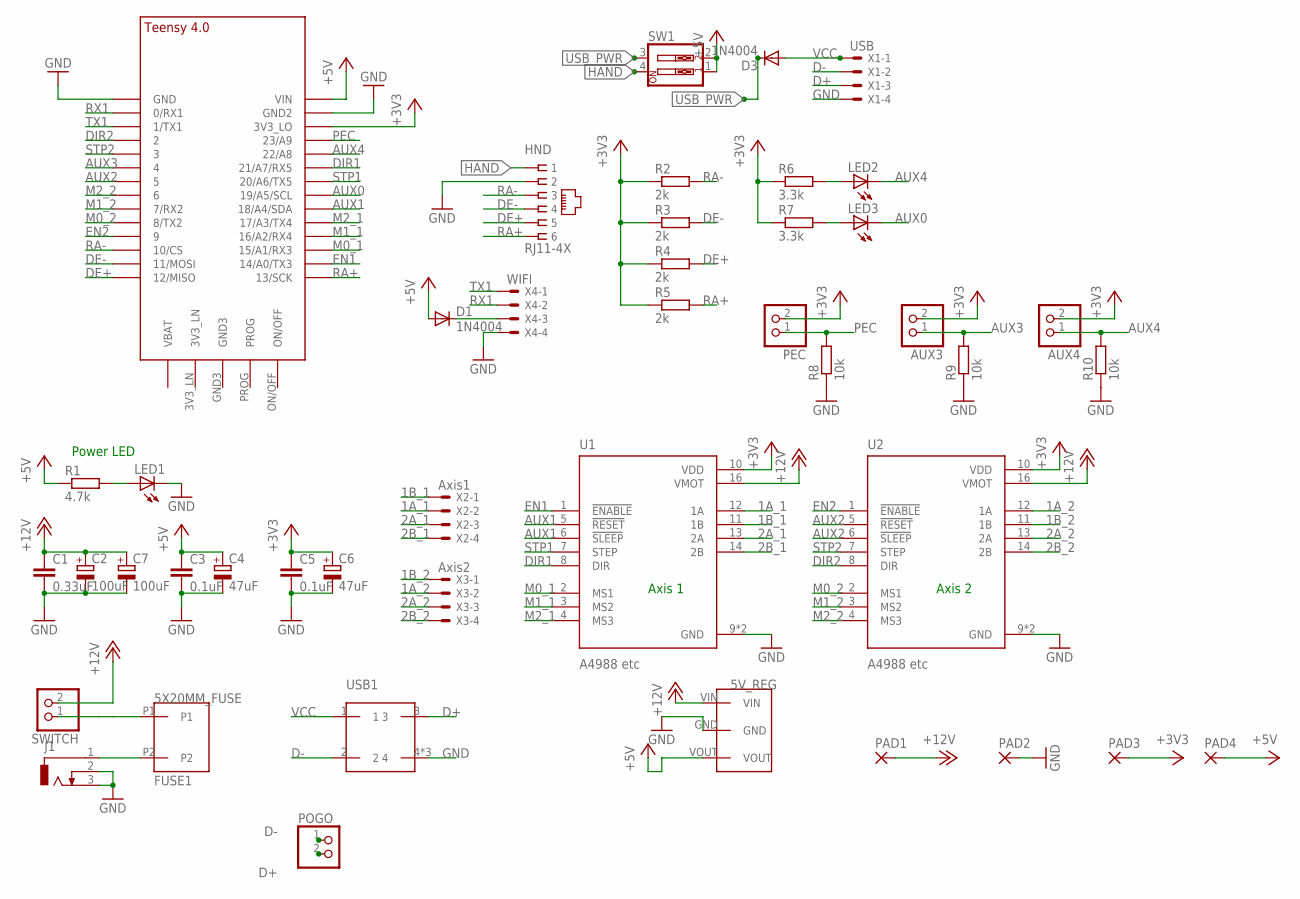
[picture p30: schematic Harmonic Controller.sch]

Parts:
5V_REG: TSR_5V
AUX3, AUX4: PINHD-1X2; 1X02
C1: 0.33uF; C050-024X044
C2, C7: 100uF; E5-8,5
C3, C5: 0.1uF; C050-024X044
C4, C6: 47uF; E5-8,5
D1, D3: 1N4004; DO41-10
FUSE1: 5X20MM_FUSE
HND: RJ11-4X; RJ11-NO_SHIELD
J1: DCJ0303
LED1, LED2, LED3: LED5MM
PAD1, PAD2, PAD3, PAD4: SMD2; SMD1,27-2,54
PEC: PINHD-1X2; 1X02
POGO: PINHD-1X2; 1X02
R1: 4.7k; 0207/7
R2, R3, R4, R5: 2k; 0207/7
R6, R7: 3.3k; 0207/7
R8, R9, R10: 10k; 0207/7
SW1: SW_DIP-2; EDG-02
SWITCH: PINHD-1X2; 1X02
U1, U2: A4988 etc; MODULE_A4988_STEPPER_MOTOR_DRIVER_CARRIER
U$1: TEENSY_4.0
USB1: USB-B_SOCKET
X1: USB; JST-XH-04-PACKAGE-ROUND-PAD
X2: Axis1; JST-XH-04-PACKAGE-LONG-PAD
X3: Axis2; JST-XH-04-PACKAGE-LONG-PAD
X4: WIFI; JST-XH-04-PACKAGE-LONG-PAD

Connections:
1A_1: U1.12 (1A), X2.2
1A_2: U2.12 (1A), X3.2
1B_1: U1.11 (1B), X2.1
1B_2: U2.11 (1B), X3.1
2A_1: U1.13 (2A), X2.3
2A_2: U2.13 (2A), X3.3
2B_1: U1.14 (2B), X2.4
2B_2: U2.14 (2B), X3.4
+3V3: AUX3.2, AUX4.2, C5.1, C6.+, PAD3.1, PEC.2, R2.1, R3.1, R4.1, R5.1, R6.1, R7.1, U1.10 (VDD), U2.10 (VDD), U$1.3V3_LO
+5V: 5V_REG.VOUT, C3.1, C4.+, D1.A, PAD4.1, R1.1, SW1.1, SW1.2, U$1.VIN
+12V: 5V_REG.VIN, C1.1, C2.+, C7.+, PAD1.1, SWITCH.2, U1.16 (VMOT), U2.16 (VMOT)
AUX0: LED3.K (C), U$1.19/A5/SCL
AUX1: U1.5 (!RESET), U1.6 (!SLEEP), U$1.18/A4/SDA
AUX2: U2.5 (!RESET), U2.6 (!SLEEP), U$1.5
AUX3: AUX3.1, R9.2, U$1.4/CANRX (4)
AUX4: AUX4.1, LED2.K (C), R10.2, U$1.22/A8
D+: POGO.2, USB1.3, X1.3
D-: POGO.1, USB1.2, X1.2
DE+: HND.5, R4.2, U$1.12/MISO
DE-: HND.4, R3.2, U$1.11/MOSI
DIR1: U1.8 (DIR), U$1.21/A7 (21/A7/RX5)
DIR2: U2.8 (DIR), U$1.2
EN1: U1.1 (!ENABLE), U$1.14/A0 (14/A0/TX3)
EN2: U2.1 (!ENABLE), U$1.9/CS (9)
GND: 5V_REG.GND, C1.2, C2.-, C3.2, C4.-, C5.2, C6.-, C7.-, HND.2, J1.2, J1.3, LED1.K (C), PAD2.1, R8.1, R9.1, R10.1, U1.9 (GND), U1.15 (GND), U2.9 (GND), U2.15 (GND), U$1.GND, U$1.GND2, USB1.4, USB1.P$1 (4), USB1.P$2 (4), X1.4, X4.4
HAND: HND.1, SW1.4
M0_1: U1.2 (MS1), U$1.15/A1 (15/A1/RX3)
M0_2: U2.2 (MS1), U$1.8 (8/TX2)
M1_1: U1.3 (MS2), U$1.16/A2 (16/A2/RX4)
M1_2: U2.3 (MS2), U$1.7 (7/RX2)
M2_1: U1.4 (MS3), U$1.17/A3 (17/A3/TX4)
M2_2: U2.4 (MS3), U$1.6
unnamed: FUSE1.P2, J1.1
unnamed: FUSE1.P1, SWITCH.1
unnamed: LED1.A, R1.2
unnamed: D1.C, X4.3
unnamed: LED2.A, R6.2
unnamed: LED3.A, R7.2
PEC: PEC.1, R8.2, U$1.23/A9
RA+: HND.6, R5.2, U$1.13/SCK
RA-: HND.3, R2.2, U$1.10/CS
RX1: U$1.0/RX (0/RX1), X4.2
STP1: U1.7 (STEP), U$1.20/A6 (20/A6/TX5)
STP2: U2.7 (STEP), U$1.3/CANTX (3)
TX1: U$1.1/TX (1/TX1), X4.1
USB_PWR: D3.C, SW1.3
VCC: D3.A, USB1.1, X1.1

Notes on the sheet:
Power LED
Axis 1
Axis 2

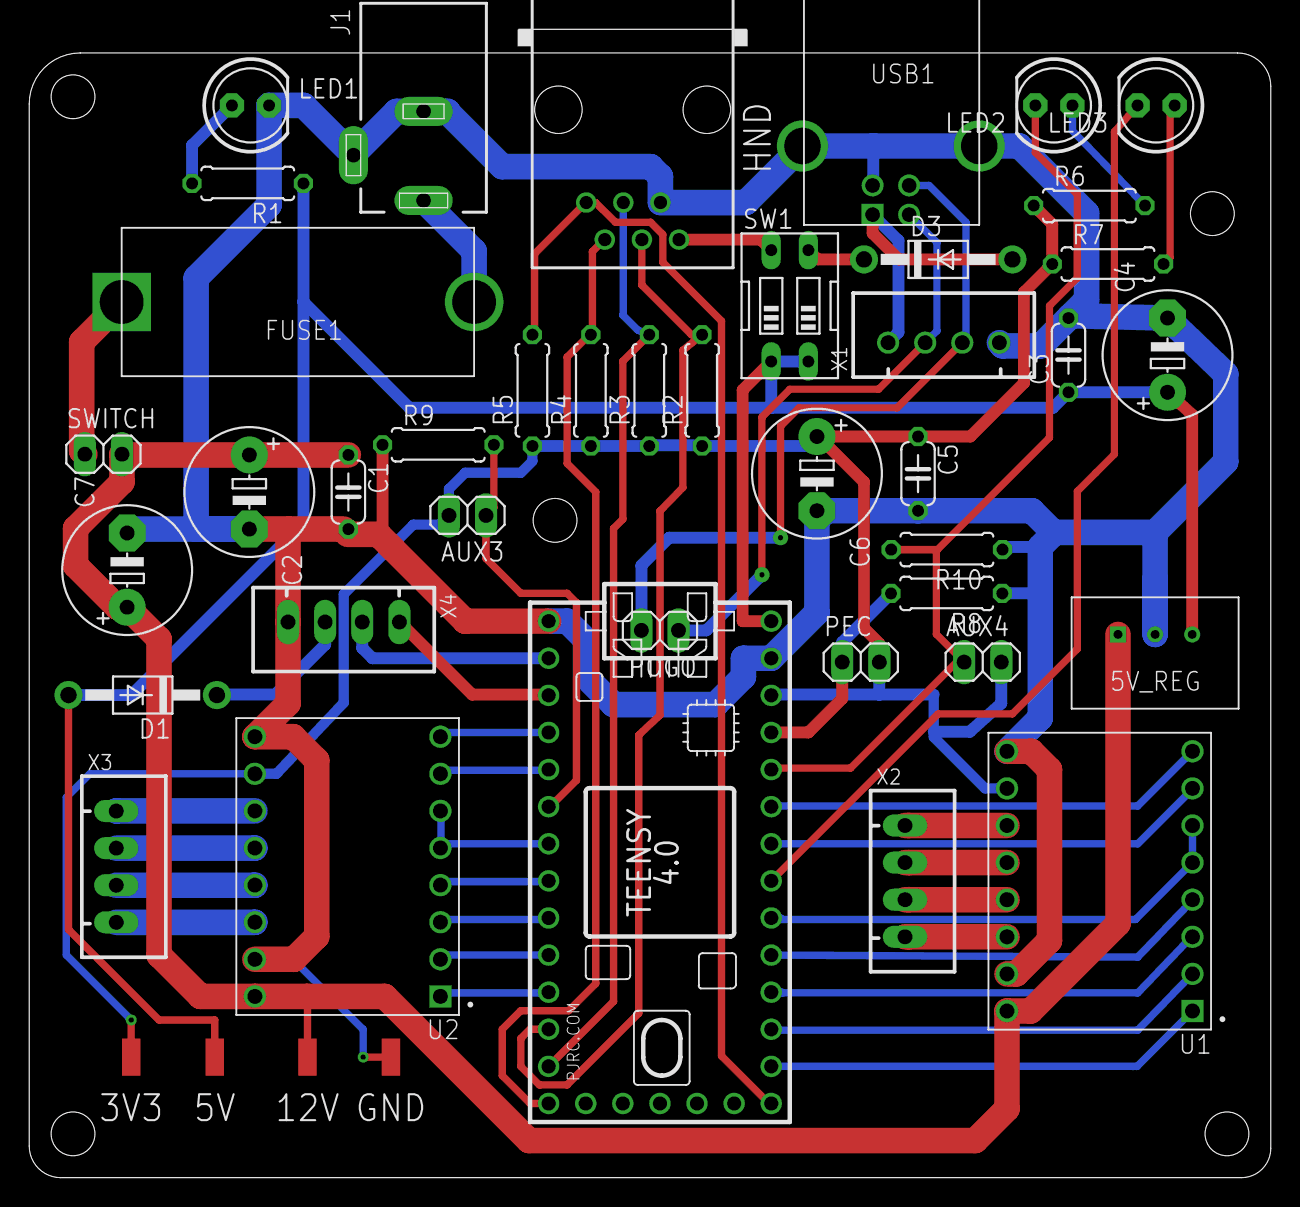
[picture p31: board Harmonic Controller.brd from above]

Board: 2 copper layers, 85.0 x 78.6 mm, 44 parts (0 on the bottom side), 47 nets.

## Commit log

2024-07-26 Add files via upload
    Electronics
    [Harmonic Controller.brd, Harmonic Controller.sch]
2024-07-26 Add files via upload
    Bonus and Future Work
    [Orange-Tube-C90_Mount.stl]
2024-07-26 Add files via upload
    Gerbers and config files for OnStep
    [DEC Shell Right.stl, DEC Shell with Aviation Port.stl, RA Shell Right.stl]
2024-07-26 Add files via upload
    Mini Mount Gerbers
    [Mini Mount Axis.stl, Mini Mount Brace.stl, Mini Mount Electronics Cover.stl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]
